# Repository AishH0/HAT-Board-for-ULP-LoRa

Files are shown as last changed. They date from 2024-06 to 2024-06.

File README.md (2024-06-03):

# ULP LoRa HAT PCB Design

The ULP LoRa HAT PCB is designed for 5V sensors to integrate with the ULP LoRa board. However, since the ULP LoRa only provides a 3.3V output voltage, 5V sensors cannot be directly integrated. This issue can be resolved by using a buck-boost converter or a boost converter circuit. In this PCB, the voltage is stepped up from 3.3V to 5V using a boost converter circuit with a TPS61202 IC. Level shifter (SN74LV1T34) is added for UART and GPIO peripherals.

# PCB Testing

- Short circuit test using Multimeter; No short ckt in the PCB.
- Provided 3.3V to the input side and Output voltage is noted (Needed output voltage is 5V); The output voltage is 6.5V.
- Varying the input voltage from 1V to 5V and the output voltage is
noted; The output voltage of the boost converter circuit is varying upto
6.5V (from the datasheet TPS61202 IC provides constant 5V.)
 - Varying the inductors and the output voltage is noted; Variable output
voltage is obtained.The PCB was modified using the TPS6120xEVM-179 datasheet. By varying the input voltage from 1V to 5V, the output voltage remains constant at 6.6V.

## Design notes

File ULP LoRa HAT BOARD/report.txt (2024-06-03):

Info: Reading netlist file '/home/aiswarya/Aiswarya Babu/Ki-CAD/ULP LoRa HAT BOARD(V2.3)/ULP LoRa HAT BOARD/ulpLoRa_charge controller HAT.net'.

Info: Using reference designators to match symbols and footprints.

Info: Processing symbol 'C4:Capacitor_SMD:C_0805_2012Metric'.
Info: Processing symbol 'J14:Connector_PinHeader_2.54mm:PinHeader_1x03_P2.54mm_Vertical'.
Info: Processing symbol 'J15:Connector_PinHeader_2.54mm:PinHeader_1x03_P2.54mm_Vertical'.
Info: Processing symbol 'J5:Connector_PinHeader_2.54mm:PinHeader_1x03_P2.54mm_Vertical'.
Info: Processing symbol 'J3:Connector_PinHeader_2.54mm:PinHeader_1x02_P2.54mm_Vertical'.
Info: Processing symbol 'J9:Connector_PinHeader_2.54mm:PinHeader_1x02_P2.54mm_Vertical'.
Info: Processing symbol 'J11:Connector_PinHeader_2.54mm:PinHeader_1x02_P2.54mm_Vertical'.
Info: Processing symbol 'J12:Connector_PinHeader_2.54mm:PinHeader_1x02_P2.54mm_Vertical'.
Info: Processing symbol 'C11:Capacitor_SMD:C_0805_2012Metric'.
Info: Processing symbol 'C2:Capacitor_SMD:C_0805_2012Metric'.
Info: Processing symbol 'J13:Connector_PinHeader_2.54mm:PinHeader_1x03_P2.54mm_Vertical'.
Info: Processing symbol 'C5:Capacitor_SMD:C_0805_2012Metric'.
Info: Processing symbol 'C6:Capacitor_SMD:C_0805_2012Metric'.
Info: Processing symbol 'C7:Capacitor_SMD:C_0805_2012Metric'.
Info: Processing symbol 'C8:Capacitor_SMD:C_0805_2012Metric'.
Info: Processing symbol 'C9:Capacitor_SMD:C_0805_2012Metric'.
Info: Processing symbol 'C10:Capacitor_SMD:C_0805_2012Metric'.
Info: Processing symbol 'C3:Capacitor_SMD:C_0402_1005Metric'.
Info: Processing symbol 'C1:Capacitor_SMD:C_0402_1005Metric'.
Info: Processing symbol 'L1:Inductor_SMD:L_0805_2012Metric'.
Info: Processing symbol 'R2:Resistor_SMD:R_0805_2012Metric'.
Info: Processing symbol 'R3:Resistor_SMD:R_0805_2012Metric'.
Info: Processing symbol 'R4:Resistor_SMD:R_0805_2012Metric'.
Info: Processing symbol 'U5:Package_TO_SOT_SMD:SOT-353_SC-70-5'.
Info: Processing symbol 'U2:Package_TO_SOT_SMD:SOT-353_SC-70-5'.
Info: Processing symbol 'U3:Package_TO_SOT_SMD:SOT-353_SC-70-5'.
Info: Processing symbol 'U4:Package_TO_SOT_SMD:SOT-353_SC-70-5'.
Info: Processing symbol 'U1:Package_SON:Texas_S-PVSON-N10_ThermalVias'.
Info: Processing symbol 'R1:Resistor_SMD:R_0805_2012Metric'.
Info: Processing symbol 'CON1:Connector_PinHeader_2.54mm:PinHeader_2x03_P2.54mm_Vertical'.
Info: Processing symbol 'CON2:Connector_PinHeader_2.54mm:PinHeader_2x03_P2.54mm_Vertical'.
Info: Processing symbol 'J1:Connector_PinHeader_2.54mm:PinHeader_1x12_P2.54mm_Vertical'.
Info: Processing symbol 'J2:Connector_PinHeader_2.54mm:PinHeader_1x12_P2.54mm_Vertical'.
Info: Processing symbol 'J8:Connector_PinHeader_2.54mm:PinHeader_1x12_P2.54mm_Vertical'.
Info: Processing symbol 'J7:Connector_PinHeader_2.54mm:PinHeader_1x12_P2.54mm_Vertical'.
Info: Processing symbol 'J6:Connector_PinHeader_2.54mm:PinHeader_1x04_P2.54mm_Vertical'.
Info: Processing symbol 'J4:Connector_PinHeader_2.54mm:PinHeader_1x04_P2.54mm_Vertical'.

Info: Total warnings: 0, errors: 0.

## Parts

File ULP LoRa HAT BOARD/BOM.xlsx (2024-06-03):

BILL OF MATERIALS
Item | Quantity | Reference | Value | PART TYPE | PCB Footprint | Manufacturer Part Number | Manfacturer Name | To be Procured by PCB Power | Remarks | Link
1 | 1 | U1 | IC REG BOOST 5V 1.2A 10VSON | Boost Converter | Boost Converter_SMD:10-VFDFN Exposed Pad | TPS61202DRCT | Texas Instruments | Yes |  | https://www.digikey.in/en/products/detail/texas-instruments/TPS61202DRCT/1536200
2 | 4 | U2, U3,U4, U5 | IC BUF NON-INVERT 5.5V SC70-5 | CMOS Logic level shifter | CMOS Logic Level shifter_SMD:SC-70-5 | SN74LV1T34DCKR | Texas Instruments | Yes |  | https://www.digikey.in/en/products/detail/texas-instruments/SN74LV1T34DCKR/4555576
3 | 5 | C2, C4, C7, C9, C11 | 0.1 uF/10 V | Capacitor | Capacitor_SMD:C_0805_2012 Metric | C0805X104K8RACAUTO | KMET | yes |  | https://in.element14.com/kemet/c0805x104k8racauto/cap-mlcc-aec-q200-0-1uf-10v-0805/dp/2905579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
4 | 4 | C6, C8, C5, C10 | 1 uF/10 V | Capacitor | Capacitor_SMD:C_0805_2012 Metric | C0805C105K8NACTU | KMET | yes |  | https://in.element14.com/kemet/c0805c105k8nactu/cap-1-f-10v-10-x8l-0805/dp/1789724?st=1uf%20capacitor
5 | 2 | C1, C3 | 10 uF/6.3 V | Capacitor | Capacitor_SMD:C_0402_1005 Metric | 490-GRM155R60J106ME05DCT-ND - Cut Tape (CT) | YAGEO | yes |  | https://www.digikey.in/en/products/detail/murata-electronics/grm155r60j106me05d/11500166
6 | 1 | R1 | 4.22 MOhms | Resistor | Resistor_SMD:R_0805_2012 Metric | CRCW08054M22FKEA | VISHAY | yes |  | https://www.mouser.in/ProductDetail/Vishay-Dale/CRCW08054M22FKEA?qs=8hp%2F0WA06VIi%252BbkTz%2FwBlA%3D%3D
7 | 1 | R2 | 470 Kohm | Resistor | Resistor_SMD:R_0805_2012 Metric | RCS0805470KJNEA | VISHAY | yes |  | https://www.mouser.in/ProductDetail/Vishay-Dale/RCS0805470KJNEA?qs=NKmfXavxMaz4UQtyFsySJA%3D%3D
8 | 1 | R3 | 2.15 Mohm | Resistor | Resistor_SMD:R_0805_2012 Metric | CRCW08052M15FKEA | VISHAY | yes |  | https://www.mouser.in/ProductDetail/Vishay-Dale/CRCW08052M15FKEA?qs=YsYeyRVmgbSu9St4fEu1Tg%3D%3D
9 | 1 | R4 | 240 Kohm | Resistor | Resistor_SMD:R_0805_2012 Metric | ERJ-HP6D2403V | Panasonic | yes |  | https://www.mouser.in/ProductDetail/Panasonic/ERJ-HP6D2403V?qs=eP2BKZSCXI7AWA9TPq7Xlg%3D%3D
10 | 1 | L1 | 2.2 uH | Inductor | Inductor_SMD:I_0805_20212Metric | LQM21PN2R2MCHD | MURATA | yes |  | https://in.element14.com/murata/lqm21pn2r2mchd/inductor-2-2uh-30mhz-0805/dp/3471401?st=2.2uh%20inductor
11 | 4 | J1, J2, J7, J8 | ~ | Connector Pin header 1*12 |  |  |  | yes | DNP
12 | 2 | CON1, CON2 | ~ | Connector pin header 2*3 |  |  |  | yes | DNP
13 | 2 | J6, J4 | ~ | Connector pin header 1*4 |  |  |  | yes | DNP
14 | 4 | J5, J13, J14, J15 | ~ | Connector Pin header 1*3 |  |  |  | yes | DNP
15 | 4 | J3, J9, J11, J12 | ~ | Connector Pin header 1*2 |  |  |  | yes | DNP

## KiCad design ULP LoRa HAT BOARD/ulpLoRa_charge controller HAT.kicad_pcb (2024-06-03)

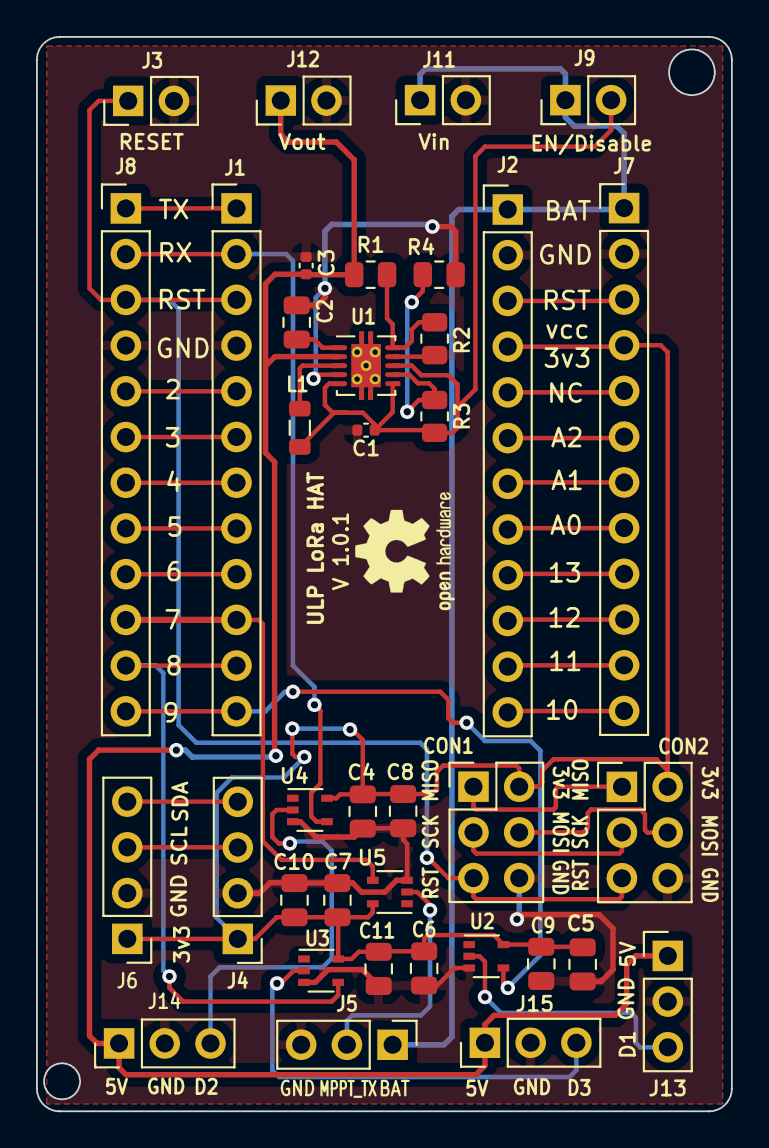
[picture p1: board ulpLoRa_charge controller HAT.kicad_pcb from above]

Board: 2 copper layers, 38.6 x 59.7 mm, 38 parts (0 on the bottom side), 38 nets.

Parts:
C1, C3: 10uF; C_0402_1005Metric
C2, C4, C7, C9, C11: 0.1uF; C_0805_2012Metric
C5, C6, C8, C10: 1uF; C_0805_2012Metric
CON1, CON2: AVR-ISP-6; PinHeader_2x03_P2.54mm_Vertical
J1, J2: Conn_01x12; PinHeader_1x12_P2.54mm_Vertical
J3: RESET; PinHeader_1x02_P2.54mm_Vertical
J4, J6: I2C; PinHeader_1x04_P2.54mm_Vertical
J5, J13, J14, J15: Conn_01x03; PinHeader_1x03_P2.54mm_Vertical
J7, J8: Conn_01x12_Pin; PinHeader_1x12_P2.54mm_Vertical
J9: EN/Disable; PinHeader_1x02_P2.54mm_Vertical
J11: Vin; PinHeader_1x02_P2.54mm_Vertical
J12: Vout; PinHeader_1x02_P2.54mm_Vertical
L1: 2.2uH; L_0805_2012Metric
R1: 4.22M; R_0805_2012Metric
R2: 470K; R_0805_2012Metric
R3: 2.15M; R_0805_2012Metric
R4: 240K; R_0805_2012Metric
U1: TPS61202DRC; Texas_S-PVSON-N10_ThermalVias
U2, U3, U4, U5: SN74LV1T34DCK; SOT-353_SC-70-5
lg1: OSHW-Logo2_7.3x6mm_SilkScreen

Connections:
/5V: C3.2, J12.1, J13.1, J14.1, J15.1, R1.1, U1.2 (VOUT)
/7: J1.10, J8.10, U5.4 (Y)
/8: J1.11, J8.11, U3.4 (Y)
/9: J1.12, J8.12, U2.4 (Y)
/BAT: J2.1, J5.1, J7.1, J9.1, J11.1
/D1: J13.3, U2.2 (A)
/D2: J14.3, U4.2 (A)
/D3: J15.3, U3.2 (A)
/MISO: CON1.1, CON2.1
/MOSI: CON1.4, CON2.4
/MPPT_TX: J5.2, U5.2 (A)
/RST: CON1.5, CON2.5, J1.3, J3.1, J8.3
/RX: J1.2, J8.2, U4.4 (Y)
/SCK: CON1.3, CON2.3
/SCL: J4.3, J6.3
/SDA: J4.4, J6.4
/VCC: C4.1, C5.1, C6.1, C7.1, C8.1, C9.1, C10.1, C11.1, CON1.2, CON2.2, J2.4, J4.1, J6.1, J7.4, U2.5 (VCC), U3.5 (VCC), U4.5 (VCC), U5.5 (VCC)
GND: C1.1, C2.2, C3.1, C4.2, C5.2, C6.2, C7.2, C8.2, C9.2, C10.2, C11.2, CON1.6, CON2.6, J1.4, J2.2, J3.2, J4.2, J5.3, J6.2, J7.2, J8.4, J11.2, J12.2, J13.2, J14.2, J15.2, R2.2, R4.2, U1.4 (PGND), U1.9 (GND), U2.3 (GND), U3.3 (GND), U4.3 (GND), U5.3 (GND)
unnamed: J1.1, J8.1
unnamed: J1.5, J8.5
unnamed: J1.6, J8.6
unnamed: J1.7, J8.7
unnamed: J1.8, J8.8
unnamed: J1.9, J8.9
unnamed: J2.3, J7.3
unnamed: J2.5, J7.5
unnamed: J2.6, J7.6
unnamed: J2.7, J7.7
unnamed: J2.8, J7.8
unnamed: J2.9, J7.9
unnamed: J2.10, J7.10
unnamed: J2.11, J7.11
unnamed: J2.12, J7.12
unnamed: C1.2, J9.2, L1.1, R3.1, U1.5 (VIN), U1.6 (EN), U1.8 (PS)
unnamed: R1.2, R2.1, U1.10 (FB)
unnamed: L1.2, U1.3 (L)
unnamed: R3.2, R4.1, U1.7 (UVLO)
unnamed: C2.1, U1.1 (VAUX)
